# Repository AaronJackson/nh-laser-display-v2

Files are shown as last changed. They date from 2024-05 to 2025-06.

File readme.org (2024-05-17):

[[.github/workflows/kicad.yaml][file:https://github.com/AaronJackson/nh-laser-display-v2/actions/workflows/kicad.yaml/badge.svg]]

This is an updated version of [[https://github.com/NottingHack/instrumentation-arduino/tree/main/LaserDisplay][LaserDisplay]] for Nottingham Hackspace
after the previous one failed for a few reasons (Arduino Due issues,
broken solder joints after a fall, etc). The previous version was on a
perf board so I decided to make a PCB. I also decided to include a
WizNet, which I haven't tested yet.

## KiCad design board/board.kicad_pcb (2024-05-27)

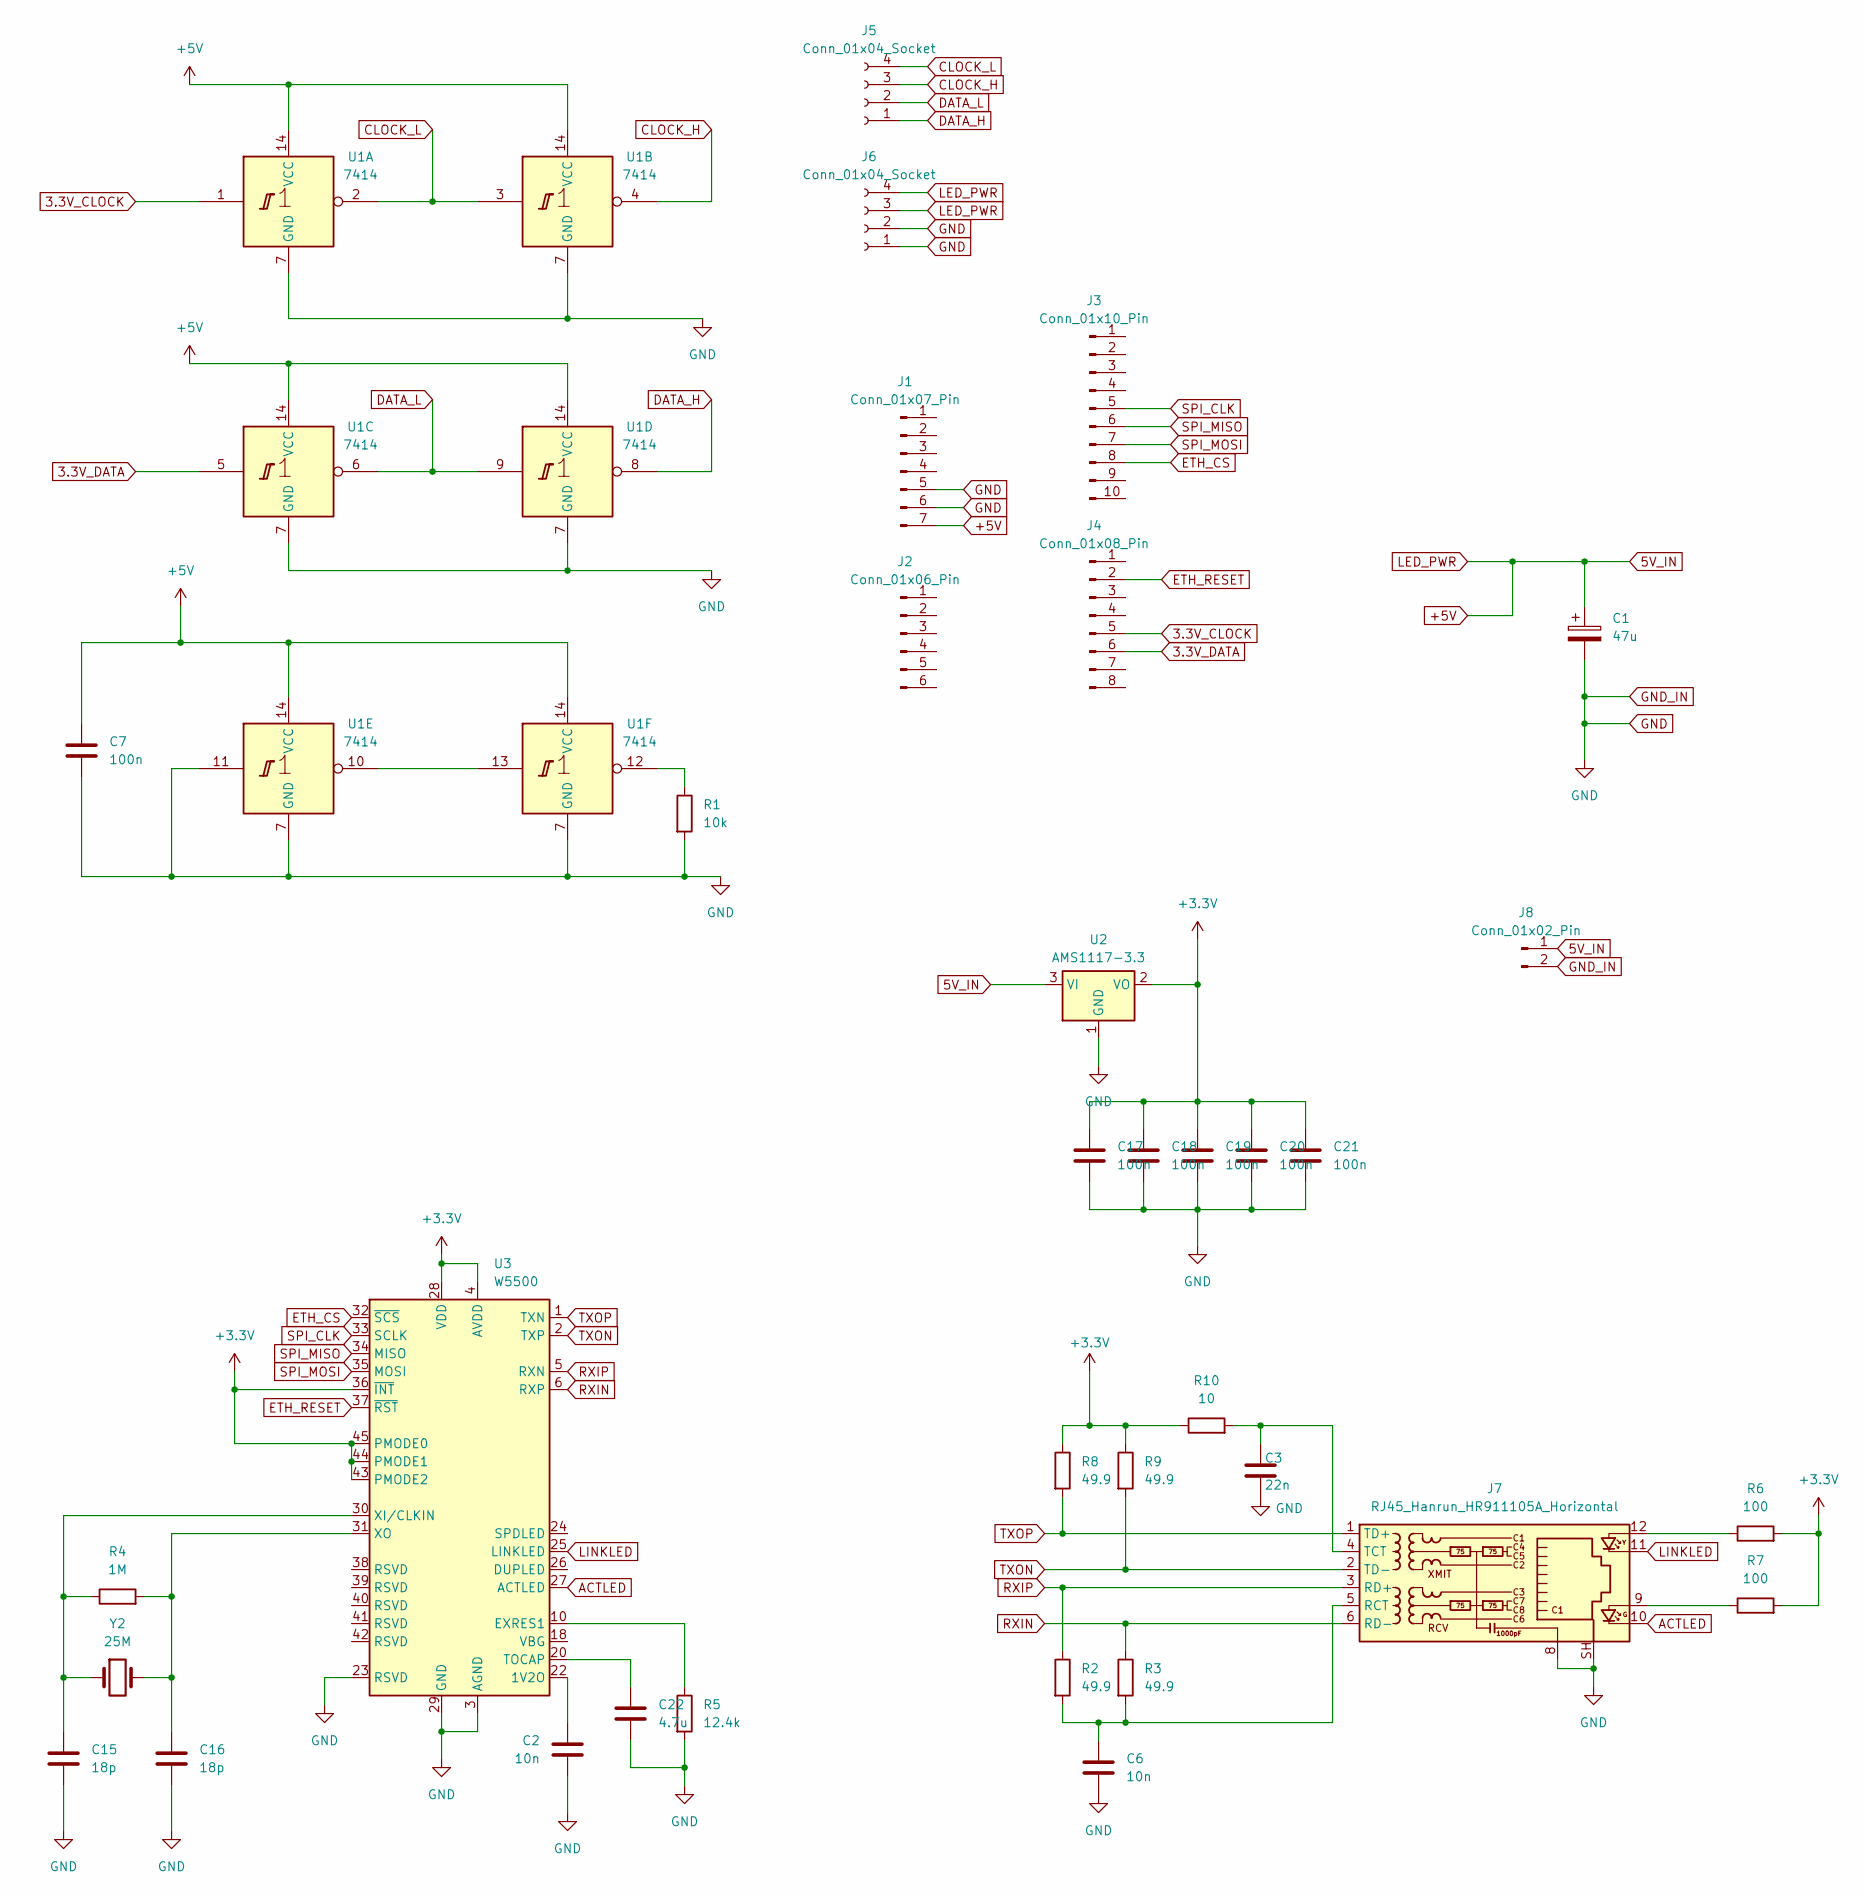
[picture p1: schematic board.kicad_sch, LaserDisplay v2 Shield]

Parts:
C1: 47u; CP_Radial_D5.0mm_P2.00mm
C2, C6: 10n; C_0603_1608Metric
C3: 22n; C_0603_1608Metric
C7, C17, C18, C19, C20, C21: 100n; C_0603_1608Metric
C15, C16: 18p; C_0603_1608Metric
C22: 4.7u; C_0603_1608Metric
J1: Conn_01x07_Pin; PinHeader_1x07_P2.54mm_Vertical
J2: Conn_01x06_Pin; PinHeader_1x06_P2.54mm_Vertical
J3: Conn_01x10_Pin; PinHeader_1x10_P2.54mm_Vertical
J4: Conn_01x08_Pin; PinHeader_1x08_P2.54mm_Vertical
J5, J6: Conn_01x04_Socket; TE_MATE-N-LOK_350211-1_1x04_P5.08mm_Vertical
J7: RJ45_Hanrun_HR911105A_Horizontal
J8: Conn_01x02_Pin; TerminalBlock_WAGO_236-103_1x03_P5.00mm_45Degree
R1: 10k; R_0603_1608Metric
R2, R3, R8, R9: 49.9; R_0603_1608Metric
R4: 1M; R_0603_1608Metric
R5: 12.4k; R_0603_1608Metric
R6, R7: 100; R_0603_1608Metric
R10: 10; R_0603_1608Metric
U1: 7414; SOIC-14_3.9x8.7mm_P1.27mm
U2: AMS1117-3.3; SOT-223-3_TabPin2
U3: W5500; LQFP-48_7x7mm_P0.5mm
Y2: 25M; Crystal_SMD_5032-2Pin_5.0x3.2mm

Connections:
3.3V_CLOCK: J4.5, U1.1
3.3V_DATA: J4.6, U1.5
+3.3V: C17.1, C18.1, C19.1, C20.1, C21.1, R6.2, R7.2, R8.1, R9.1, R10.1, U2.2 (VO), U3.4 (AVDD), U3.8 (AVDD), U3.11 (AVDD), U3.15 (AVDD), U3.17 (AVDD), U3.21 (AVDD), U3.28 (VDD), U3.36 (~INT), U3.43 (PMODE2), U3.44 (PMODE1), U3.45 (PMODE0)
+5V: C1.1, C7.1, J1.7, J6.3, J6.4, J8.1, U1.14 (VCC), U2.3 (VI)
ACTLED: J7.10, U3.27 (ACTLED)
CLOCK_H: J5.3, U1.4
CLOCK_L: J5.4, U1.2, U1.3
DATA_H: J5.1, U1.8
DATA_L: J5.2, U1.6, U1.9
ETH_CS: J3.8, U3.32 (~SCS)
ETH_RESET: J4.2, U3.37 (~RST)
GND: C1.2, C2.2, C3.2, C6.1, C7.2, C15.2, C16.2, C17.2, C18.2, C19.2, C20.2, C21.2, C22.2, J1.5, J1.6, J6.1, J6.2, J7.8, J7.SH, J8.2, R1.2, R5.2, U1.7 (GND), U1.11, U2.1 (GND), U3.3 (AGND), U3.9 (AGND), U3.14 (AGND), U3.16 (AGND), U3.19 (AGND), U3.23 (RSVD), U3.29 (GND), U3.48 (AGND)
LINKLED: J7.11, U3.25 (LINKLED)
unnamed: J7.9, R7.1
unnamed: J7.12, R6.1
unnamed: C6.2, J7.5 (RCT), R2.2, R3.2
unnamed: C3.1, J7.4 (TCT), R10.2
unnamed: R1.1, U1.12
unnamed: U1.10, U1.13
unnamed: C2.1, U3.22 (1V2O)
unnamed: R5.1, U3.10 (EXRES1)
unnamed: C22.1, U3.20 (TOCAP)
unnamed: C15.1, R4.1, U3.30 (XI/CLKIN), Y2.1
unnamed: C16.1, R4.2, U3.31 (XO), Y2.2
RXIN: J7.6 (RD-), R3.1, U3.6 (RXP)
RXIP: J7.3 (RD+), R2.1, U3.5 (RXN)
SPI_CLK: J3.5, U3.33 (SCLK)
SPI_MISO: J3.6, U3.34 (MISO)
SPI_MOSI: J3.7, U3.35 (MOSI)
TXON: J7.2 (TD-), R9.2, U3.2 (TXP)
TXOP: J7.1 (TD+), R8.2, U3.1 (TXN)

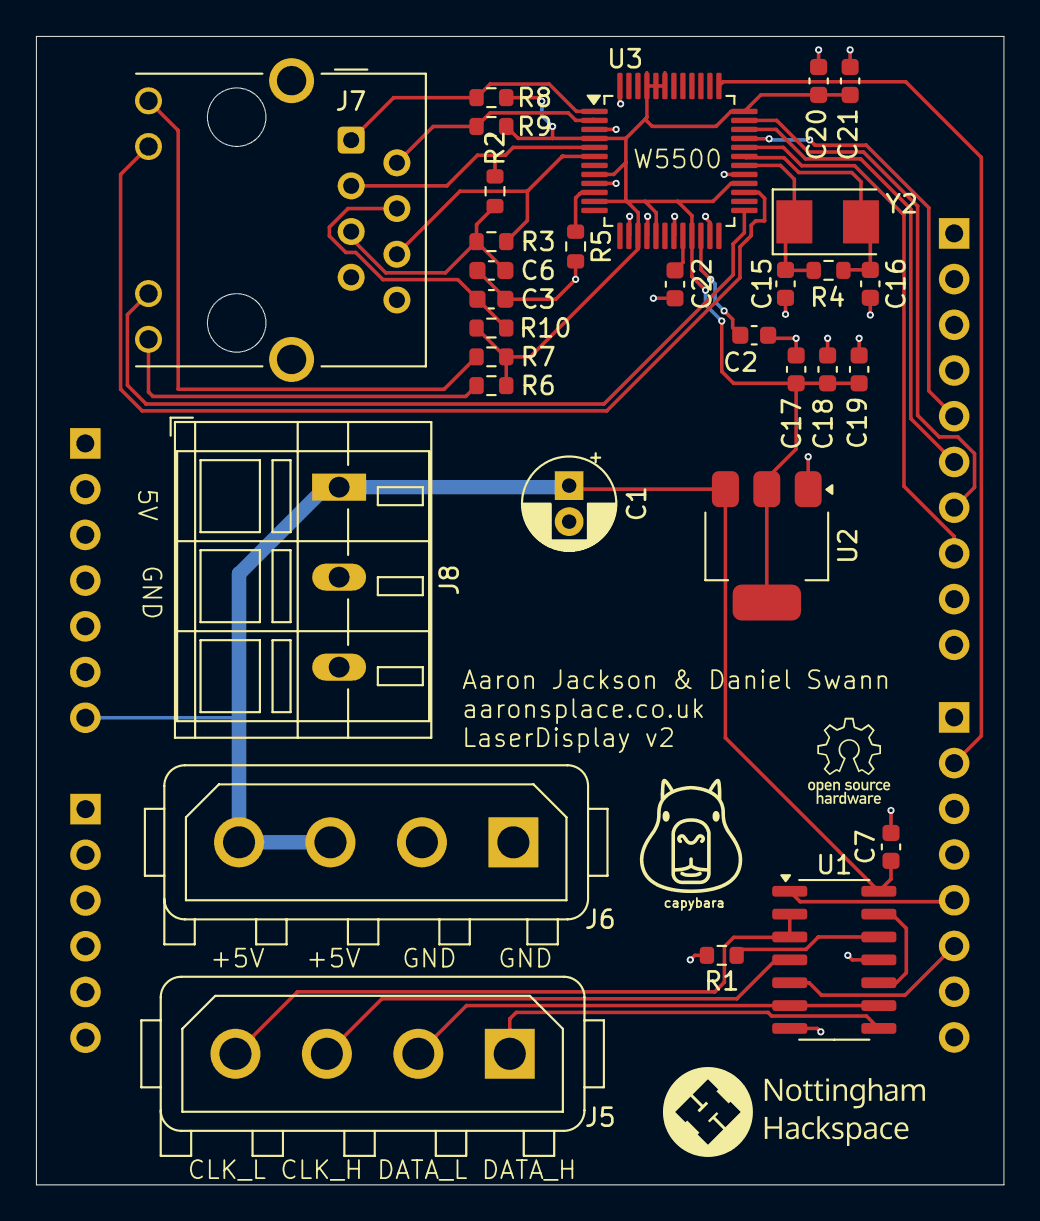
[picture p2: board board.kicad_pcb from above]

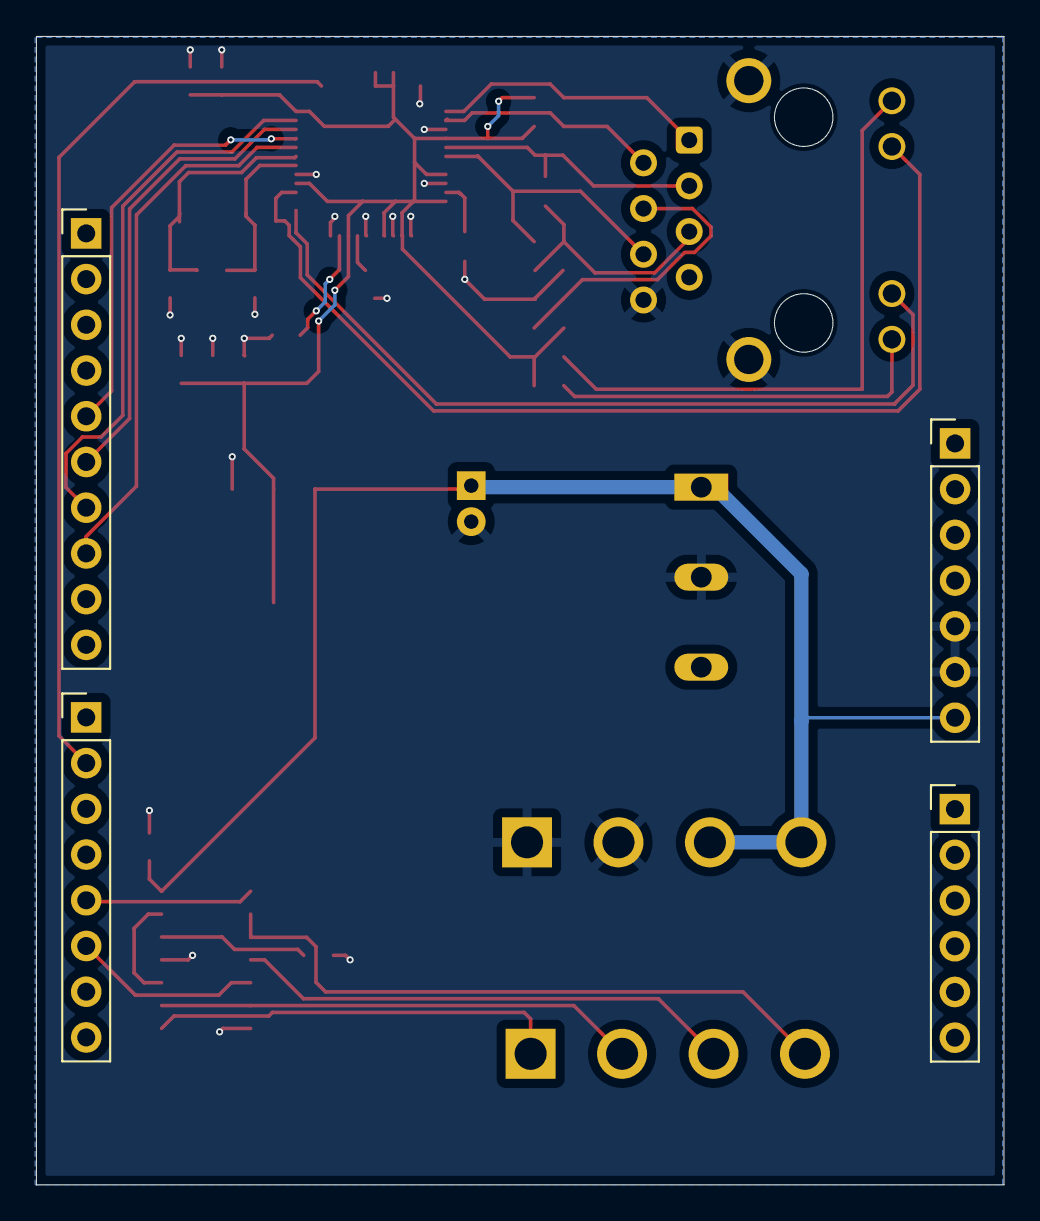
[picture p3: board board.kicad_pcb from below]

Board: 2 copper layers, 53.8 x 63.8 mm, 35 parts (4 on the bottom side), 31 nets.

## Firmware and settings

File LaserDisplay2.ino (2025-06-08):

#include <Adafruit_GFX.h>
#include "Font5x7Fixed.h"
#include "FspTimer.h"
#include "Ethernet.h"
#include "PubSubClient.h"
#include <ArduinoJson.h>
#include "OneWire.h"
#include "DallasTemperature.h"

#define NAME "LaserDisplay"

#define DATA R_PORT1, 5
#define CLK R_PORT1, 4

// NOP to skip a cycle
#define NOP __asm__("nop")
// Set a PIN high or low
#define _PIN_SET(port, pin, value) if (value) { port->POSR = bit(pin);} else { port->PORR = bit(pin); }
#define PIN_SET(...) _PIN_SET(__VA_ARGS__)
// Set a pin to be an output
#define _OUTPUT(port, pin) port->PDR |= bit(pin)
#define OUTPUT(...) _OUTPUT(__VA_ARGS__)
// Clocking and writing macros
#define NOP4 NOP; NOP; NOP; NOP
#define NOPS NOP4; NOP4; NOP4; NOP4;
#define CLOCK PIN_SET(CLK, HIGH); NOPS; NOPS; PIN_SET(CLK, LOW);
#define WRITE_BIT(bit) PIN_SET(DATA, bit); CLOCK

#define WIDTH 16 * 12
#define HEIGHT 16
#define MQTT_HOST "192.168.0.1"
#define MQTT_PORT 1883

#define NOWNEXT "nh/bookings/boxfordlaser/nownext"
#define DISCORD_RX "nh/discord/rx"
#define DOORBELL_TOPIC "nh/gk/DoorButton"
#define STATUS_TOPIC "nh/status"
#define TEMP_TOPIC "nh/temp"

#define TEMP_ID "9999000000000001"
OneWire oneWire(5);
DallasTemperature sensors(&oneWire);
unsigned long last_temp_poll = 0;
float last_temp = 0;

byte mac[] = { 0xA0, 0x3F, 0x9A, 0x86, 0xAF, 0xD3 };
byte ip[] = {192, 168, 0, 24};

void mqtt_callback(char* topic, byte* payload, unsigned int length);

GFXcanvas1 buffer(WIDTH, HEIGHT);
volatile uint8_t* rawBuffer;
FspTimer timer;
int row;  // used by drawRowISR
EthernetClient ethClient;
PubSubClient mqtt(ethClient);
unsigned long last_mqtt_poll = 0;
unsigned long clear_after = 0;

char nowNextJson[512];
char discordMessage[4096];
char discordUsername[64];
char discordChannel[64];
char doorbell[32];

byte encode_row(byte row) {
  byte enc_row = 0;
  byte nibble1, nibble2;

  nibble1 = row;
  nibble2 = ~row & 0x0F;

  enc_row = nibble1;
  enc_row |= ((nibble2 << 4) & 0xF0);
  return enc_row;
}

void drawRowISR(timer_callback_args_t __attribute((unused)) * p_args) {
  volatile uint8_t* ptr;

  byte rowIdx = encode_row(row);
  for (int i = 0; i < 8; i++) {
    byte b = (rowIdx << i) & 128;
    WRITE_BIT(b);
  }

  for (int col = 0; col < 16 * 12; col++) {
    if (col >= WIDTH) {
      WRITE_BIT(0);
    } else {
      ptr = &rawBuffer[(col / 8) + row * ((WIDTH + 7) / 8)];
      byte b = ((*ptr) & (0x80 >> (col & 7))) != 0;
      WRITE_BIT(b);
    }
  }

  row++;
  if (row == 16) row = 0;
}

bool beginTimer(float rate) {
  uint8_t timer_type = AGT_TIMER;
  int8_t tindex = FspTimer::get_available_timer(timer_type);
  if (tindex < 0) {
    tindex = FspTimer::get_available_timer(timer_type, true);
  }
  if (tindex < 0) {
    return false;
  }

  if (!timer.begin(TIMER_MODE_PERIODIC, timer_type, tindex, rate, 0.0f, drawRowISR)) {
    return false;
  }

  if (!timer.setup_overflow_irq()) {
    return false;
  }

  if (!timer.open()) {
    return false;
  }

  if (!timer.start()) {
    return false;
  }

  return true;
}

void checkMqtt() {
  if (mqtt.connected()) return;
  // mqtt.setBufferSize(2048);

  mqtt.setServer(MQTT_HOST, MQTT_PORT);

  mqtt.setCallback(mqtt_callback);

  while (!mqtt.connected()) {
    String clientId = "LaserDisplay";
    clientId += String(random(0xffff), HEX);

    if (mqtt.connect(clientId.c_str())) {
      Serial.println("MQTT has connected!");
      mqtt.subscribe(NOWNEXT);
      mqtt.subscribe(DISCORD_RX "/#");
      mqtt.subscribe(DOORBELL_TOPIC);
      mqtt.subscribe(STATUS_TOPIC "/req");

      mqtt.publish("nh/discord/tx/pm/asjackson", NAME " - Restarted");
      mqtt.publish("nh/irc/tx/pm/asjackson", NAME " - Restarted");
    }
  }
}

void setup() {
  OUTPUT(DATA);
  OUTPUT(CLK);
  
  rawBuffer = buffer.getBuffer();
  row = 0;

  beginTimer(2000);

  Serial.begin(115200);
  Serial.println("Hello world.");

  buffer.setFont(&Font5x7Fixed);
  buffer.setTextSize(1);

  buffer.setTextSize(1);
  buffer.setCursor(0, 7);
  buffer.print("LaserDisplay v2");

  sensors.begin();

  //Ethernet.init();
  Ethernet.begin(mac, ip);

  if (Ethernet.hardwareStatus() == EthernetNoHardware) {
    buffer.print("Ethernet shield was not found.");
    while (true);
  } else if (Ethernet.hardwareStatus() == EthernetW5500) {
    buffer.setCursor(0, 16);
    buffer.print("W5500 Ethernet controller detected.");
    Serial.print("W5500 Ethernet controller detected.");
  } else {
    Serial.print("Ethernet hardwareStatus() unknown.");
  }

  delay(1000);
  buffer.fillRect(0, 8, WIDTH, 16, 0x00);
  buffer.setCursor(0, 16);

  buffer.print(Ethernet.localIP());
  Serial.println(Ethernet.localIP());

  delay(300);
  checkMqtt();
}

void drawNowNext() {
  StaticJsonDocument<200> doc;
  DeserializationError error = deserializeJson(doc, nowNextJson);

  const char* now = doc["now"]["display_name"];
  const char* next = doc["next"]["display_name"];
  const char* next_time = doc["next"]["display_time"];

  char line1[80];
  char line2[80];

  if (strcmp(now, "none") != 0) {
    sprintf(line1, "%s now", now);
  } else {
    sprintf(line1, "No active booking.");
  }

  if (strcmp(next, "none") != 0) {
    sprintf(line2, "%s @ %s", next, next_time);
  } else {
    sprintf(line2, "No future bookings.");
  }

  // buffer.fillRect(0, 0, WIDTH, HEIGHT, 0x00);
  buffer.fillScreen(0x00);
  buffer.setCursor(0, 7);
  buffer.print(line1);
  buffer.setCursor(0, 16);
  buffer.print(line2);

  char temperature[10];
  sprintf(temperature, "%.2f c", last_temp);
  buffer.setCursor(155, 7);
  buffer.print("Chiller:");
  buffer.setCursor(160, 16);
  buffer.print(temperature);
}

void drawDiscord() {
  buffer.fillScreen(0x0000);
  buffer.setCursor(0, 8);
  buffer.setTextWrap(true);

  char message[2048];
  sprintf(message, "%s in %s> %s", discordUsername, discordChannel, discordMessage);

  String _message = String(message);
  _message.replace("😄", ":D");
  _message.replace("🙂", ":)");
  _message.replace("😭", ":'(");
  _message.replace("😢", ":'(");
  _message.replace("\n\n", "\n");

  buffer.print(_message.c_str());
}

void drawDoorbell() {
  buffer.fillScreen(0x0000);
  buffer.setCursor(5, 16);
  buffer.setTextSize(2);
  buffer.print(doorbell);
  buffer.setTextSize(1);
}

void loop() {
  checkMqtt();

  if (micros() - last_mqtt_poll > 1e6) {
    mqtt.loop();
    last_mqtt_poll = micros(); 
  }

  if (micros() > clear_after) {
    drawNowNext();
    clear_after = micros() + 10e6;
  }

  if (micros() - last_temp_poll > 15e6) {
    sensors.requestTemperatures();
    last_temp = sensors.getTempCByIndex(0);
    Serial.println(last_temp);
    char stemp[24];
    snprintf(stemp, sizeof(stemp), "%s:%.2f", TEMP_ID, last_temp);
    mqtt.publish(TEMP_TOPIC, stemp);
    last_temp_poll = micros();
  }
}

void mqtt_callback(char* topic, unsigned char* payload, unsigned int length) {
  if (strcmp(topic, STATUS_TOPIC "/req") == 0 && memcmp(payload, "STATUS", length) == 0) {
    mqtt.publish(STATUS_TOPIC "/res", "Running: " NAME);
    return;
  }

  if (strcmp(topic, NOWNEXT) == 0) {
    memset(nowNextJson, 0, sizeof nowNextJson);
    strncpy(nowNextJson, (const char*)payload, length);
    drawNowNext();
    return;
  }

  if (strncmp(topic, DISCORD_RX, strlen(DISCORD_RX)) == 0) {
    memset(discordUsername, 0, sizeof discordUsername);
    memset(discordChannel, 0, sizeof discordChannel);
    memset(discordMessage, 0, sizeof discordMessage);

    // I hate string processing in C so much.
    char suffix[100];
    strcpy(suffix, topic + strlen(DISCORD_RX) + 1);
    char *sep = strchr(suffix, '/');
    if ((sep-suffix) < 0) return; // no username part (e.g. "nh/discord/rx/general")
    strncpy(discordChannel, suffix, sep-suffix);
    strcpy(discordUsername, sep + 1);

    if (length > 4095) length = 4095;
    strncpy(discordMessage, (const char*)payload, length);
    clear_after = micros() + 10e6;
    drawDiscord();
    return;
  }

  if (strncmp(topic, DOORBELL_TOPIC, strlen(DOORBELL_TOPIC)) == 0) {
    strncpy(doorbell, (const char*)payload, length);
    clear_after = micros() + 10e6;
    drawDoorbell();
    return;
  }
}

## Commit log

2024-05-16 first commit, early stages
    [board.kicad_pcb, board.kicad_sch]
2024-05-16 Small changes prior to ordering
    [board.kicad_pcb, board.kicad_sch]
2024-05-17 Add ERC ignores for various floating pins
    [board.kicad_pcb, board.kicad_sch]
2024-05-27 Removal of C4 and C5 from Ethernet rx lines
    [board.kicad_pcb, board.kicad_sch]
2024-05-27 Changes post PCB build
2025-06-08 Add DS18B20 for Laser chiller temperature
